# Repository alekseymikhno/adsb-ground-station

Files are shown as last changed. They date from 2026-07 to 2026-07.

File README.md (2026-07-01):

# ADS-B 1090 MHz Ground Station (PDX Airspace)

A 1090 MHz ADS-B receiver system tracking aircraft over Portland, OR, paired with an in-progress custom RF front end and an LLM-based anomaly-detection pipeline.

## Status

- **Pi 5 receiver**: Live and collecting flight data (May–July 2026)
- **Custom RF front end**: In design: 1090 MHz filter-LNA (TA1090EC SAW + PGA-103+). Schematic and QucsStudio simulation complete (~13.3 dB cascade gain, ~3.2 dB NF); not yet sent to fabrication.
- **Anomaly detection**: LLM analysis pipeline in development

## What It Does

1. **RF capture**: 1090 MHz antenna -> TA1090EC SAW filter -> PGA-103+ LNA -> Nooelec NESDR SMArt v5 SDR
2. **Decode**: Raspberry Pi 5 runs dump1090 to decode Mode S / ADS-B messages in real time
3. **Analysis**: LLM-based anomaly detector flags unusual flight patterns over PDX airspace
4. **Output**: Logged to SQLite, served via web dashboard with a Tar1090 UI

## Folder Structure

- `hardware/rf-frontend/` — KiCad schematic, PCB layout, component libraries
  - `kicad/` — schematic and board files
  - `simulation/` — QucsStudio S-parameter simulations and results
- `software/receiver/` — dump1090 config, startup scripts
- `software/anomaly-detection/` — analysis pipeline code
- `docs/` — datasheets, system diagrams, build photos
- `data/rf-measurements/` — NanoVNA measurement data (S-parameter sweeps)

## Key Specs

**RF Front End: 1090 MHz Filter-LNA (TA1090EC + PGA-103+)**

| Parameter | Value | Source |
|---|---|---|
| Cascade gain @ 1.09 GHz | ~13.3 dB | Friis analysis (sim + datasheet) |
| System noise figure | ~3.2 dB | Friis cascade |
| LNA gain (S21) @ 1.09 GHz | ~15.6 dB | QucsStudio simulation |
| LNA noise figure | ~0.9 dB | PGA-103+ datasheet |
| Input match (S11) @ 1.09 GHz | −13.7 dB | QucsStudio simulation |
| Front filter | TA1090EC SAW, ~2.3 dB insertion loss | TAI-SAW datasheet |
| Topology | SAW filter → PGA-103+ E-pHEMT LNA, bias-tee | — |
| Port impedance | 50 Ω in/out (no external matching) | — |
| Supply | 4.5 V via bias-tee choke | — |

*Simulated/calculated values pending hardware validation. NanoVNA measurement data in `/data/rf-measurements/`.*

**Receiver**

- Nooelec NESDR SMArt v5 SDR with software-activatable bias tee
- dump1090 decode on Raspberry Pi 5
- Coverage: PDX airspace (~130-140 nm radius)

## Design Notes

The front end places a SAW filter ahead of the LNA (filter-first topology). This trades a small noise-figure penalty, the filter's ~2.3 dB insertion loss adds directly to system NF per the Friis equation, for out-of-band rejection of FM broadcast, cellular, and GSM signals that would otherwise overload the SDR in a high-RF environment near an airport. The PGA-103+ was chosen for its sub-1 dB noise figure and 50 Ω matched ports requiring no external matching network.

## Roadmap

1. Finalize schematic and PCB layout; export Gerbers
2. Fabricate and assemble the filter-LNA board
3. NanoVNA validation against simulated gain / match
4. Integrate measured front-end performance into system characterization
5. Complete anomaly-detection pipeline and dashboard

## References

- [Mode S / ADS-B protocol (mode-s.org)](https://mode-s.org/)
- [dump1090 (flightaware fork)](https://github.com/flightaware/dump1090)
- [RTL-SDR Blog V4](https://www.rtl-sdr.com/rtl-sdr-blog-v4-release/)
- [PGA-103+ datasheet (Mini-Circuits)](https://www.minicircuits.com/pdfs/PGA-103+.pdf)

## License

MIT

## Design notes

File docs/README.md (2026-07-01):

# Documentation

System diagrams, photos, and reference materials.

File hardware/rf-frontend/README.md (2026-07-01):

# RF Front End

KiCad schematic and PCB design for the 1090 MHz ADS-B filter-LNA-filter chain.
- Target NF: ~2.85 dB
- Target gain: +32 dB
- Status: Design phase, pending PCB fabrication

See `/docs/friis-cascade-analysis.pdf` for the full cascade analysis.

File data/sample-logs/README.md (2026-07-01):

# Sample Logs

Small sample of decoded ADS-B messages and flight tracks for reference.

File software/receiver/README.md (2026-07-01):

# Receiver

dump1090 configuration and setup scripts for the Raspberry Pi 5.

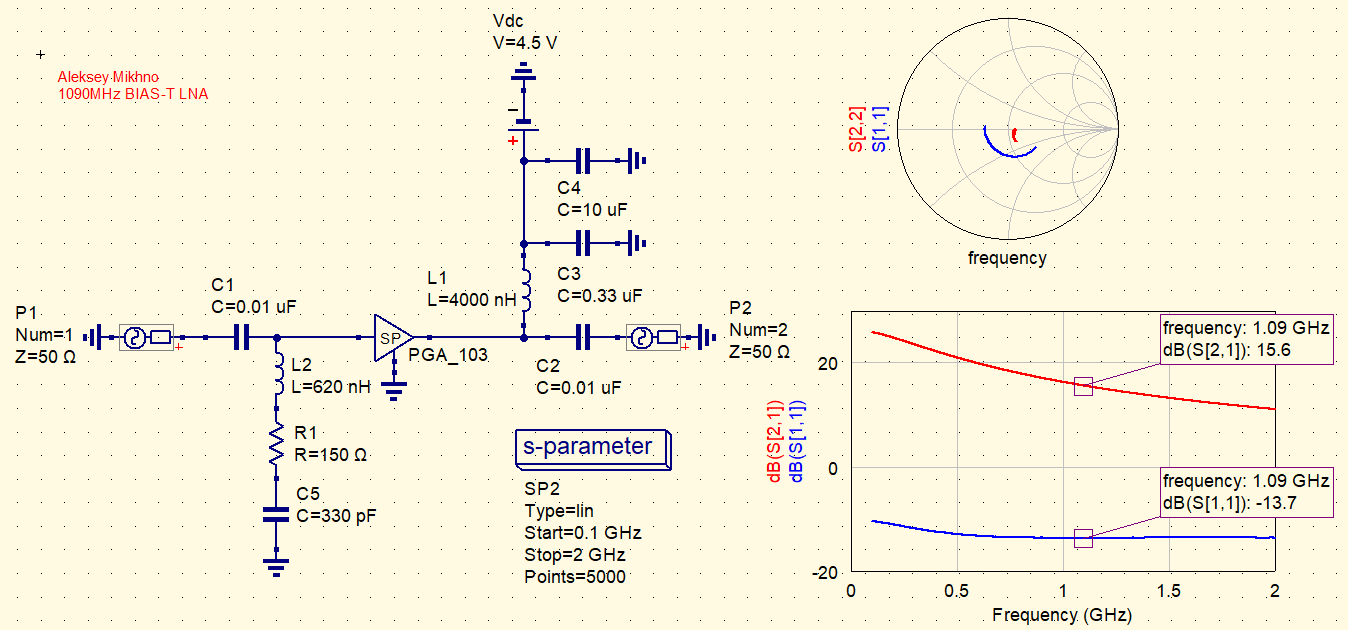
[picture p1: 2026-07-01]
hardware/rf-frontend/simulation/qucsStudio/Gain-at-1090MHz-simulation.png

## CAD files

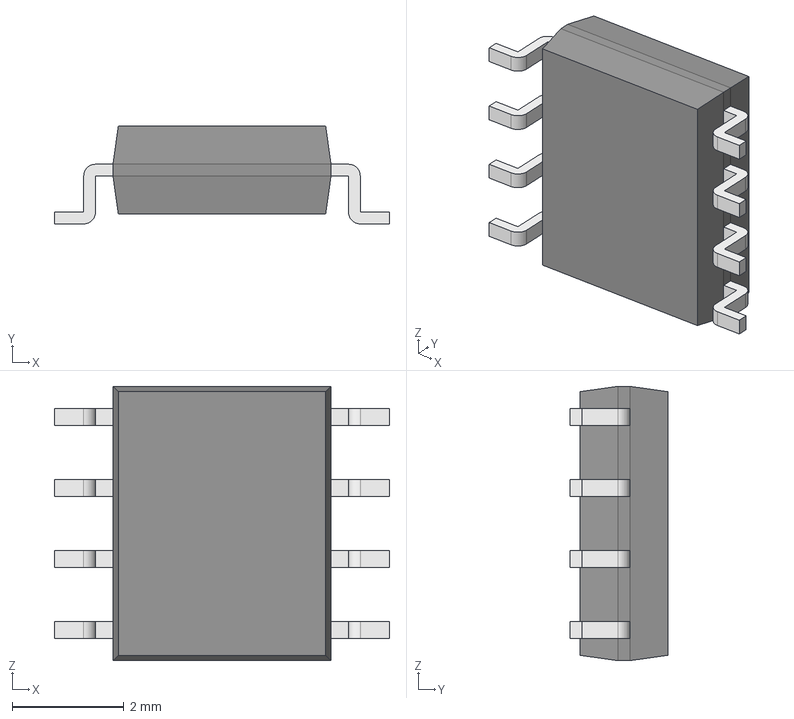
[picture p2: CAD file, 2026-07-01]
hardware/rf-frontend/kicad/PGA-103_/PGA-103_.step
5.99 x 1.75 x 4.91 mm
Body001 (Mirror #1) x 4
XY-plane x 12
X-axis x 12

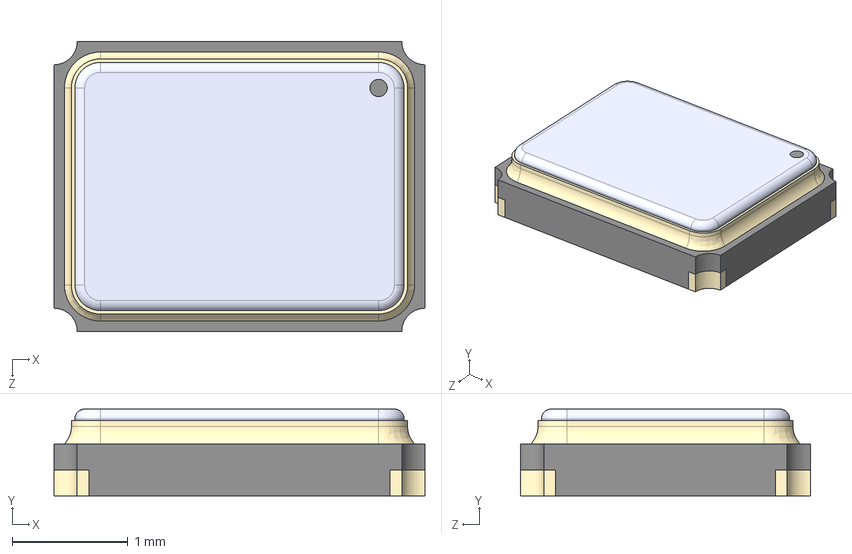
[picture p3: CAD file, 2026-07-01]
hardware/rf-frontend/kicad/TA1090EC/C3E-30.000-12-3030-X-R.step
3.20 x 0.75 x 2.50 mm

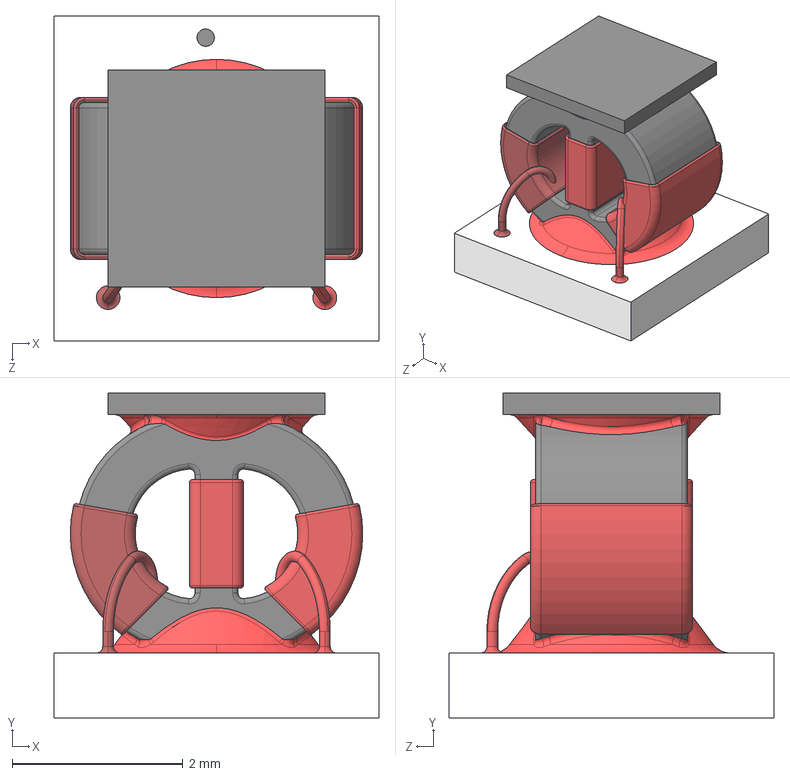
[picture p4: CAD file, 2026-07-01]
hardware/rf-frontend/kicad/TCCH-80/TCCH-80.step
3.81 x 3.81 x 3.81 mm

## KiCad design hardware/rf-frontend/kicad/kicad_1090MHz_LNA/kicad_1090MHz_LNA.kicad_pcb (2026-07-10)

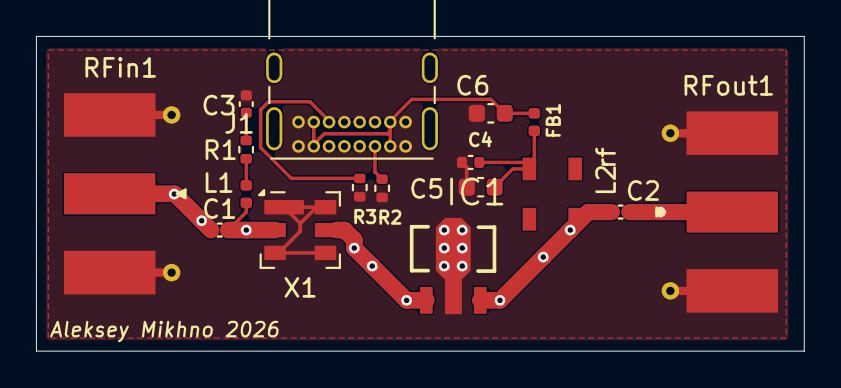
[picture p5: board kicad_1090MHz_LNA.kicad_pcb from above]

Board: 2 copper layers, 42.7 x 17.5 mm, 17 parts (0 on the bottom side), 12 nets.

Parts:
C1, C2, C3, C4: C; C_0402_1005Metric
C5, C6: C; C_0603_1608Metric
FB1: FerriteBead; L_0402_1005Metric
IC1: PGA-103_; SOT-89
J1: USB_C_Receptacle_USB2.0_16P; USB_C_Receptacle_GCT_USB4085
L1: L; L_0402_1005Metric
L2: TCCH-80; GU1604
R1, R2, R3: R; R_0402_1005Metric
RFin1: 732511150; SMA_Molex_73251-1153_EdgeMount_Horizontal
RFout1: 732511150; SMA_Molex_73251-1153_EdgeMount_Horizontal
X1: STA1090EC; Filter_SAW-6_3.8x3.8mm

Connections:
GND: C3.1, C4.2, C5.2, C6.2, IC1.2 (GND), J1.A1 (GND), J1.A12 (GND), J1.B1 (GND), J1.B12 (GND), R2.1, R3.1, RFin1.2, RFout1.2, X1.1 (GND), X1.3 (GND), X1.4 (GND), X1.6 (GND)
unnamed: C1.1, RFin1.1
unnamed: C2.2, RFout1.1
unnamed: C3.2, R1.2
unnamed: C6.1, FB1.1, J1.A4 (VBUS), J1.A9 (VBUS), J1.B4 (VBUS), J1.B9 (VBUS)
unnamed: IC1.1 (IN), X1.5 (OUT)
unnamed: C2.1, IC1.3 (OUT/DC), L2.P$1 (RF)
unnamed: J1.A5 (CC1), R2.2
unnamed: J1.B5 (CC2), R3.2
unnamed: L1.2, R1.1
unnamed: C4.1, C5.1, FB1.2, L2.P$3 (DC)
unnamed: C1.2, L1.1, X1.2 (IN)

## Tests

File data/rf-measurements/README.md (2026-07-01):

# RF Measurements

NanoVNA-H4 S-parameter measurements for the 1090 MHz filter-LNA-filter front end characterization.

## Files

- `antenna_direct.csv` — S21/S11 direct antenna measurement (full band)
- `antenna_direct_g40.csv` — S21/S11 direct antenna with 40 dB gain setting
- `through_module.csv` — S21/S11 measurement through complete filter-LNA-filter module
- `through_module_g40.csv` — S21/S11 measurement through module with 40 dB gain setting

## Measurement Setup

- **VNA**: NanoVNA-H4
- **Reference plane**: 50Ω at SMA connectors
- **Frequency span**: 0.5–2.0 GHz (5000 points)
- **Port 2 attenuation**: 30 dB pad used for LNA gain measurements to protect VNA input
- **Calibration**: SOLT calibration performed over full sweep range with attenuator in place

## Notes

Antenna direct measurements characterize the SAW filter response in isolation. Through-module measurements show the complete signal chain performance including the PMA4-33GLN+ LNA stage.

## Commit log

2026-07-01 Add KiCad schematic, PCB layout, and component libraries for 1090 MHz PGA-103+ LNA
    [1090MHz_LNA.kicad_pcb, 1090MHz_LNA.kicad_sch, C3E-30.000-12-3030-X-R.step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]
2026-07-01 Add measurement CSV files
    [antenna_direct.csv, antenna_direct_g40.csv, through_module.csv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]
2026-07-01 Correct RF front-end specs: filter-LNA topology with PGA-103+ (13.3 dB gain, 3.2 dB NF)
2026-07-10 Redesign: USB-C powered PGA-103+ LNA PCB (replaces bias-tee topology). Schematic complete (0 ERC), layout with 0.93mm GCPW on 1mm FR4, dual-layer ground pour + via stitching, Gerbers generated for JL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
2026-07-10 Update RF frontend KiCad: completed USB-C LNA board with routing, pours, via stitching, and Gerbers
    [1090MHz_LNA.kicad_pcb, 1090MHz_LNA.kicad_sch, kicad_1090MHz_LNA.kicad_pcb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]
